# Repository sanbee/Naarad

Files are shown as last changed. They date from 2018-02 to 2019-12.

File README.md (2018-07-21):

# Naarad
A simple house monitor and control system. 

The *Naarad* system is a network of remote Nodes with a radio operating
in the [ISM band](https://en.wikipedia.org/wiki/ISM_band) and a Base
Station with an [RFM69CW](http://www.hoperf.com/rf_transceiver/modules/RFM69CW.html) (RFM) packet radio, currently connected to an
Arduino UNO.  The UNO talks to a Linux-based computer (currently a
Raspberry PI (RPi)) via the serial connection.  The RPi also listens
for incoming socket connections.  Commands for the *Naarad* network
are either generated at the RPi or arrive at the socket (e.g. from a
remotely connected device).  Commands meant for the UNO or the remote
Nodes are sent to the UNO via the serial connection.  The server on
the UNO then transmits the commands for the remote Nodes via the RFM
or via another radio for remote [OOK](https://en.wikipedia.org/wiki/On-off_keying)
devices.  Similarly, information from remote Nodes is received at the 
UNO via the RFM and immediately transferred to the RPi for consumption 
via the serial connection. The block level system diagram looks like this:

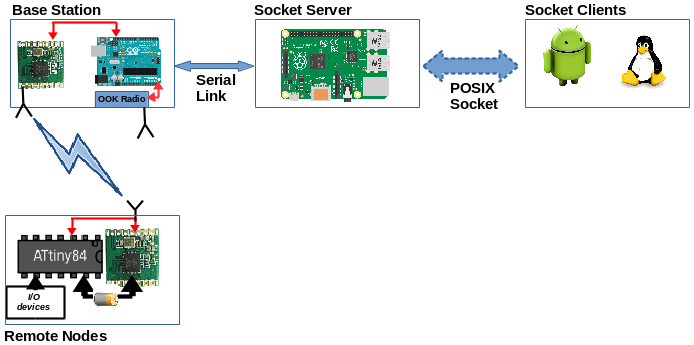
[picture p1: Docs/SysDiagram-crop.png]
SysDiagram


This repository has the code for the three components of the Naarad system: 
  * The code running on the MCUs on the remote nodes is in the [Nodes](Nodes) directory
  * The code running on the Arduino UNO on the Base Station is in the [BaseStation](BaseStation) directory
  * The code running on the central socket server (Raspberry Pi) is in the [RPi](RPi) directory

### Resources
The communication with the RFM is done using the
[JeeLib](https://github.com/jcw/jeelib) library from
[JeeLabs](https://jeelabs.org).

The communication hardware on the remote Nodes is derived from the
[TinyTx](https://nathan.chantrell.net/tinytx-wireless-sensor) design.
For programming the ATTiny84 using an Arduino, I followed the
instructions from [here](https://nathan.chantrell.net/20120225/an-attiny-based-wireless-temperature-sensor/).

[This](http://www.gammon.com.au/power) article by [Nick Gammon](http://www.gammon.com.au/forum/bbshowbio.php?bbuser_id=1) is an excellent resource for techniques to reduce power consumption on MCU. While the code here is for Arduino (Atmega328P), some of the techniques apply to other Atmel processors.  A similar article sepecifically for ATTiny84 would be great.  This also has a post with very useful information about batteries (including self-drainage rates etc.).

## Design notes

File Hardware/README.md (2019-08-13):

# Naarad Hardware

|  Prototype | Version 1 |
| :---: | :---: |
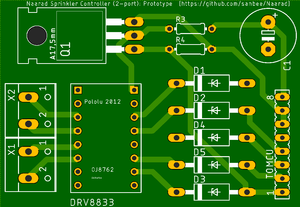
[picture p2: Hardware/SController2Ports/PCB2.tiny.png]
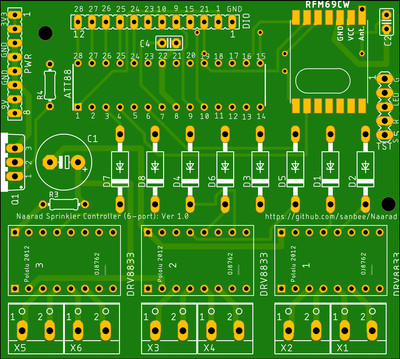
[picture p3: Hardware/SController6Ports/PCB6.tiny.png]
|   |   |

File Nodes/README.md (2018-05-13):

  * TinyTX: Code that runs on Tx-only remote monitor nodes
  * TinyL9110S: Code for the Sprinkler controller node.  This node
    does full duplex communication and uses the L9110S H-bridge to
    control a DC latching solenoid valve.
```
- From <ROOT>/
// ATMEL ATTINY84 / ARDUINO
//
//                           +-\/-+
//                     VCC  1|    |14  GND
//             (D  0)  PB0  2|    |13  PA0  (D 10)        AREF
//             (D  1)  PB1  3|    |12  PA1  (D  9) 
//             (D 11)  PB3  4|    |11  PA2  (D  8) 
//  PWM  INT0  (D  2)  PB2  5|    |10  PA3  (D  7) 
//  PWM        (D  3)  PA7  6|    |9   PA4  (D  6) 
//  PWM        (D  4)  PA6  7|    |8   PA5  (D  5)        PWM
//                           +----+
```

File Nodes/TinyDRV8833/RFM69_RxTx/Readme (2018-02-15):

This dir. has the sketch development for
 - Program the ATT84 on the RFM69 board to work in both Rx and Tx.
 - Identify command-packets from the server (NodeID 5) meant for
   itself (Node ID 15) and process them by LOW/HIGH on (A2,D8, Pin11)
   and (A3,D7, Pin12) on ATT84.

Branches:

master: Has the first working version
   SrvTxRetry: o Has ver0 code for pkt. ACK and retry at the server
                       o Takes only simple command: RFM_SEND NODE CMD

        FullCmd: o Has retry (SrvTxRetry)              [THIS IS THE VERSION ON THE MCU] 03FEB2018
	               o RFM_SEND CMD NODE PORT TIMEOUT
		       o SYS commands: Only SYS_SHUTDOWN_INTERVAL
	                  tested

              FullCmdTO_Untested:  o Has full command support
                                                     (FullCmd)
						  o UNTESTED code for
                                                     SYS_SHUTDOWN_INTERVAL_MULTIPLIER
						  o UNTESTED code for enabling valveTimeout

                                                     SYS_SHUTDOWN_INTERVAL_MULTIPLIER
                                                     is required since Sleepy::loseSomeTime()
                                                     can take a maximum of 60000 (60 sec.).  
                                                     With an 8-bit multiplier, it can remain shut
                                                     for max. of 60x255 sec.

                                                     Attempt for valveTimeout is to issue a
						     CLOSE command valveTimeout min. after
						     a OPEN command was issued. Default
						     value is 30min (1800000 milli sec).  If a
						     value of 0 is recevied as part of the
						     RFM_SEND command, it defaults to 30min.
	             
                                                  o unoserver2.ino has the ping command
 						     implemented and tested.  This is the
						     sketch running on Arduino now (5Feb2018).
TODO:
-------

0. The temperature reading does not look right.  Fix it.

1. Along with the command, send info. about when to toggle the
    solenoid.

2. Use an ACK-based communication with the base-station.  Tell the
    station the state of the solenoid.  This will need parsing of the
    payload values at the base station as well.

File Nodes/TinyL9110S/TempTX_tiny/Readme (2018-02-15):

A sketch to make the RFM69 break-out board act as a simple Naarad Tx-only node.

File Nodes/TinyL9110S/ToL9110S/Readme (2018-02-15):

This sketch is a standalone test for ATT84 to toggle the solenoid via L9110S connected to it on pins (11,12).
This just toggles the Pin11 and Pin12 every 10 sec.

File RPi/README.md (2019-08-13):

# Naarad Host Server

The block level diagram of the server looks like this:

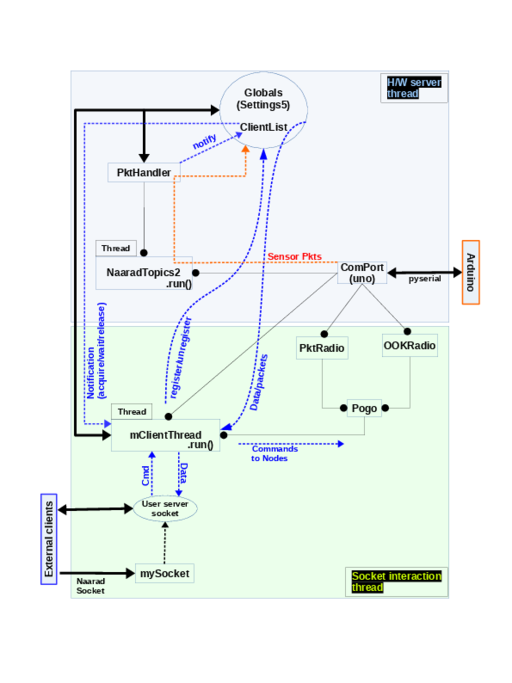
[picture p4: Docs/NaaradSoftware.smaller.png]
SysDiagram


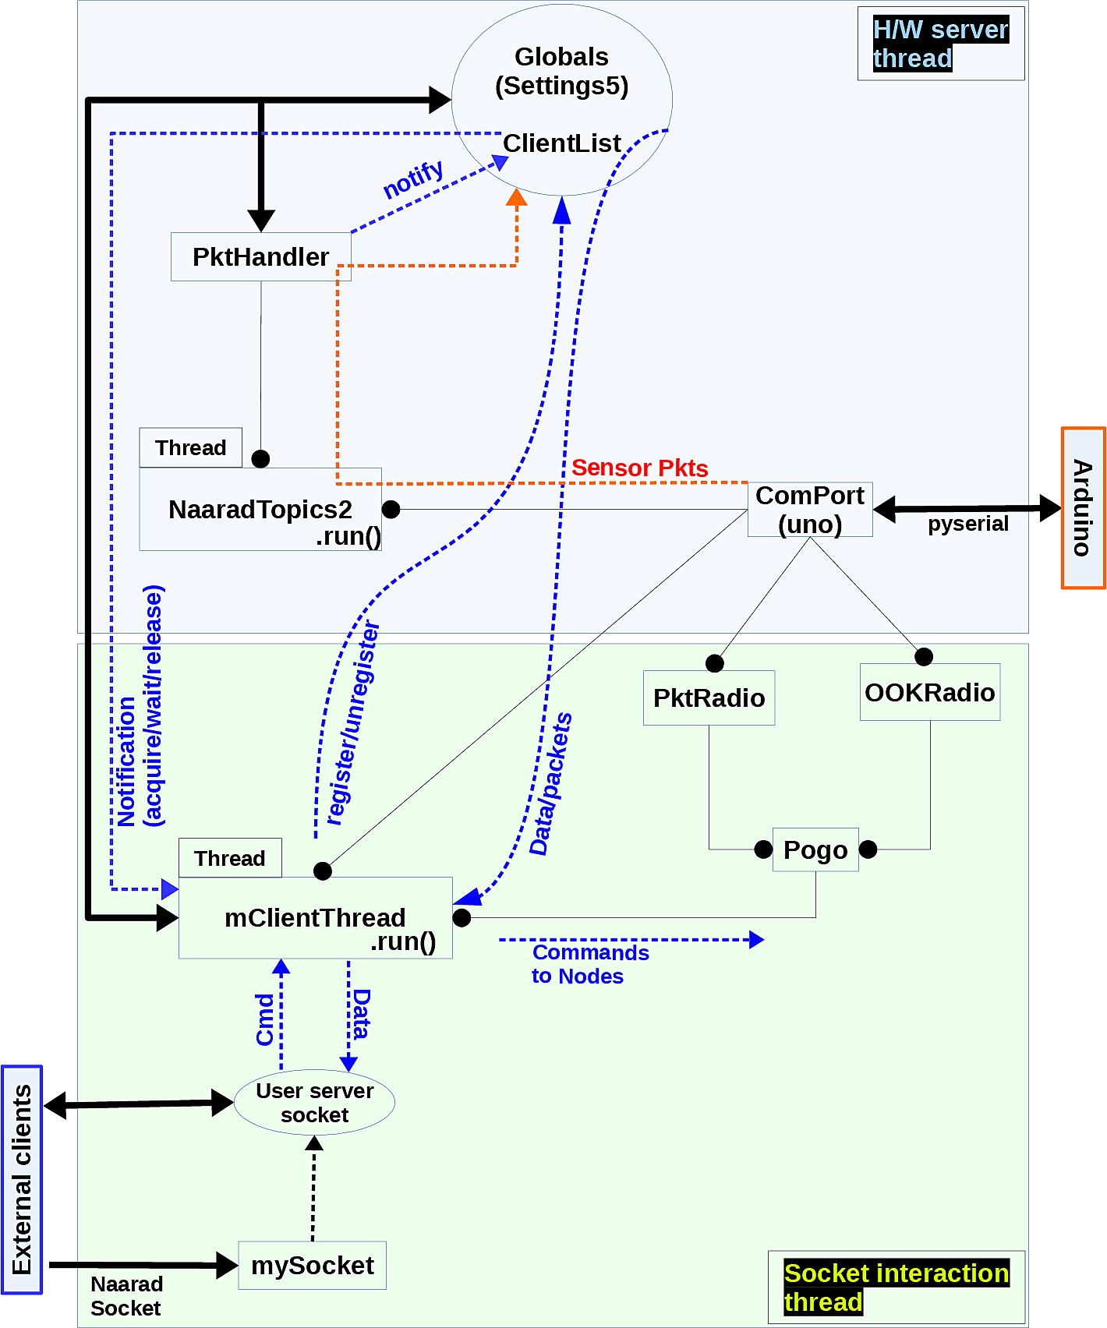
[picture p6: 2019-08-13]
Docs/NaaradSoftware.png

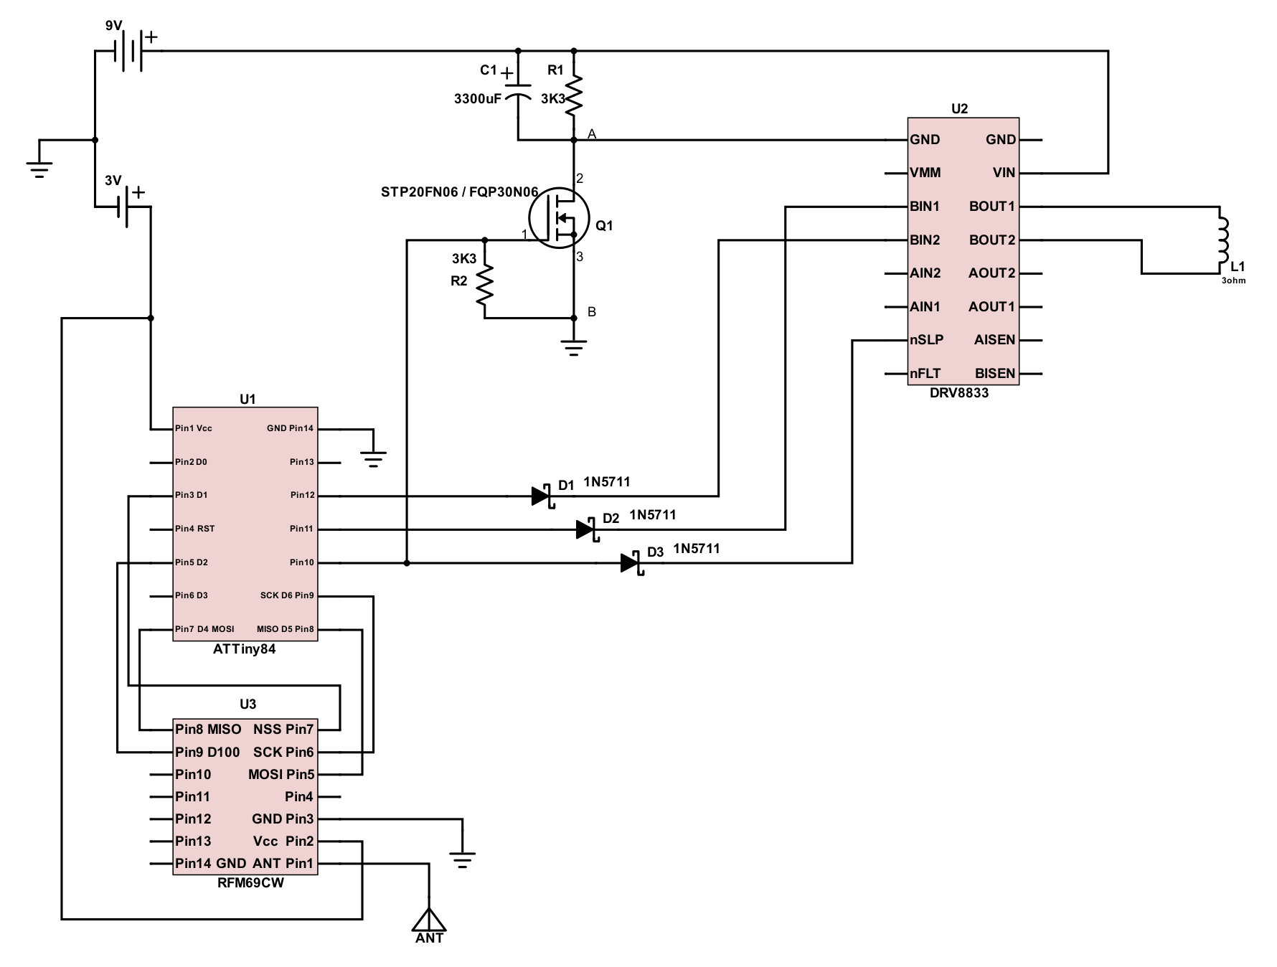
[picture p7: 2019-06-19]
Docs/SController-8833.png

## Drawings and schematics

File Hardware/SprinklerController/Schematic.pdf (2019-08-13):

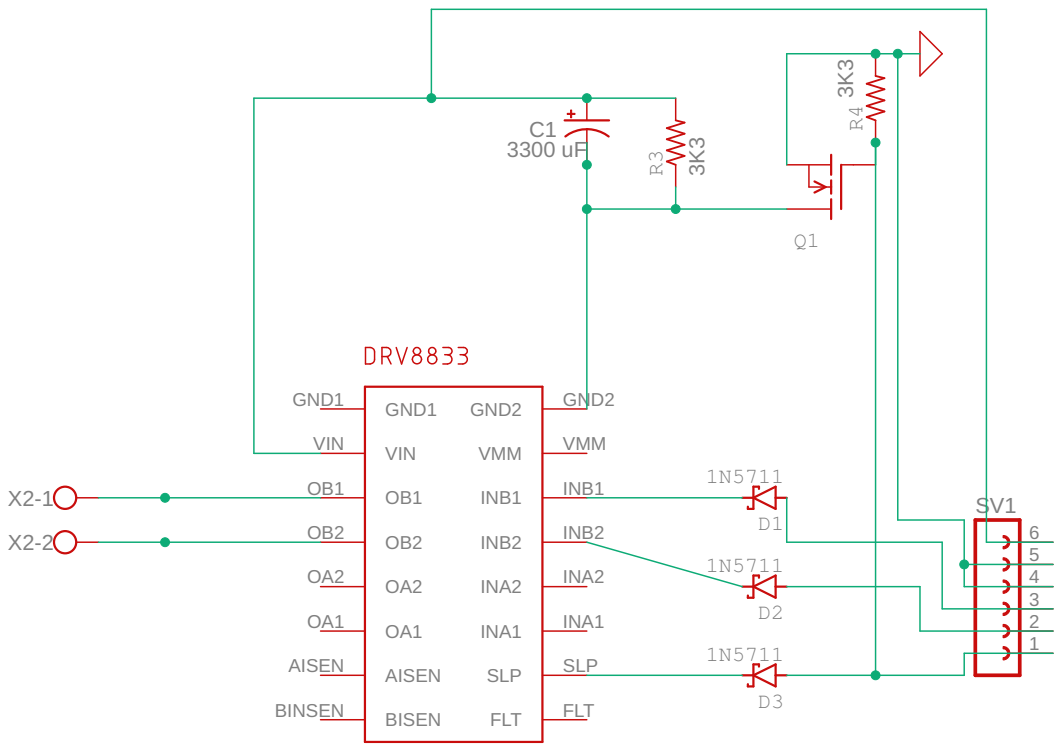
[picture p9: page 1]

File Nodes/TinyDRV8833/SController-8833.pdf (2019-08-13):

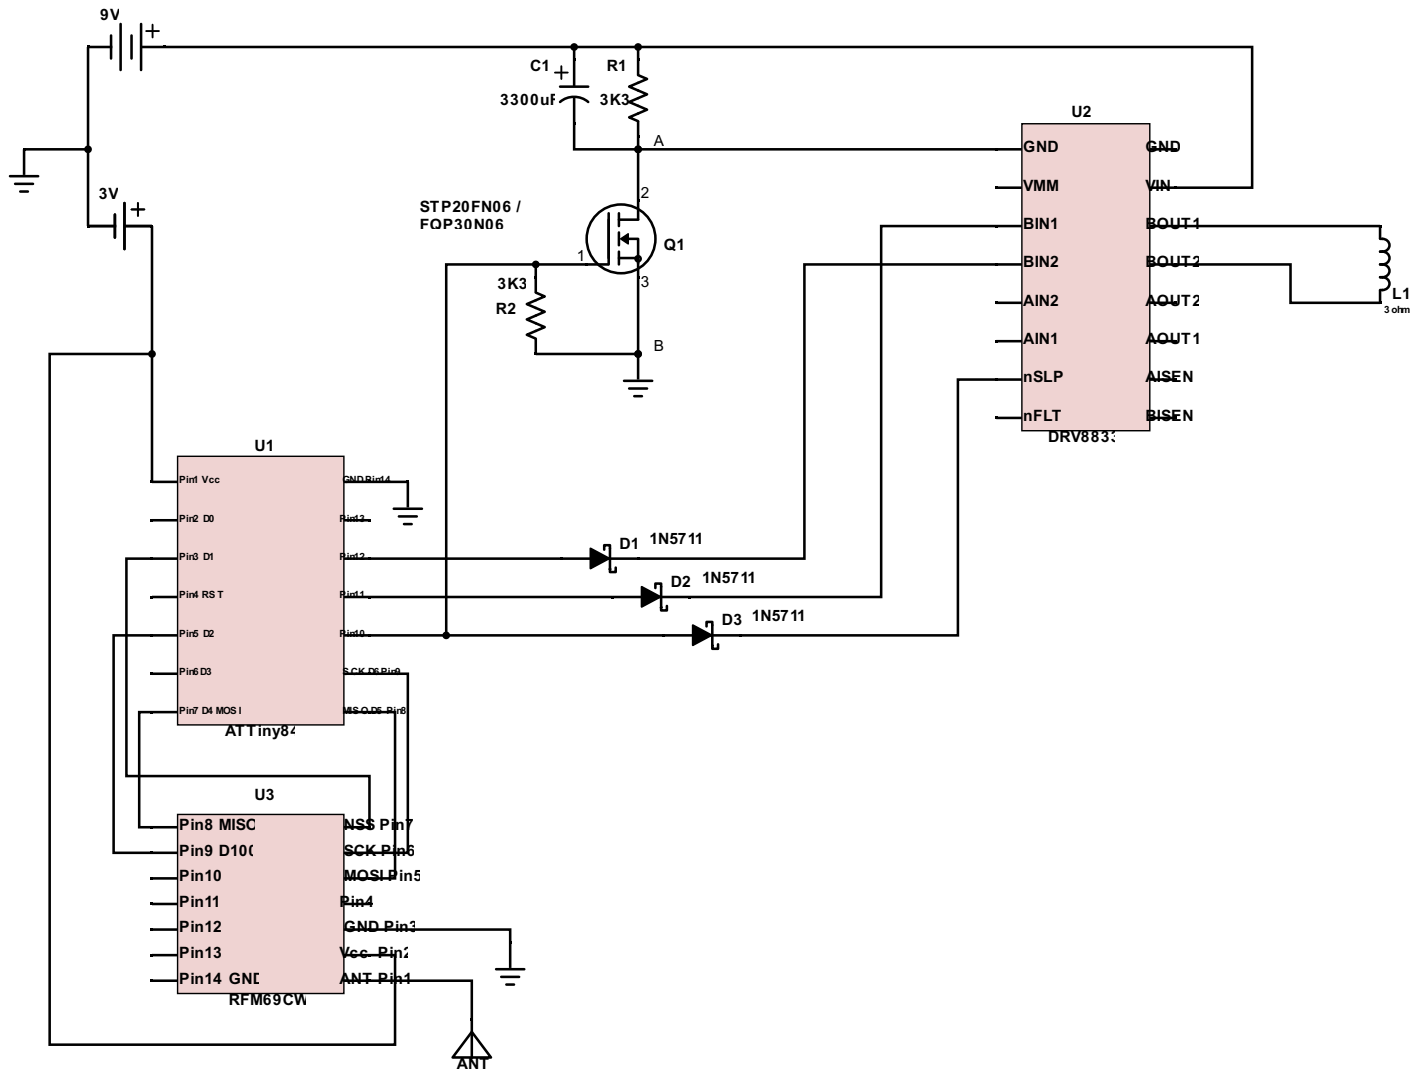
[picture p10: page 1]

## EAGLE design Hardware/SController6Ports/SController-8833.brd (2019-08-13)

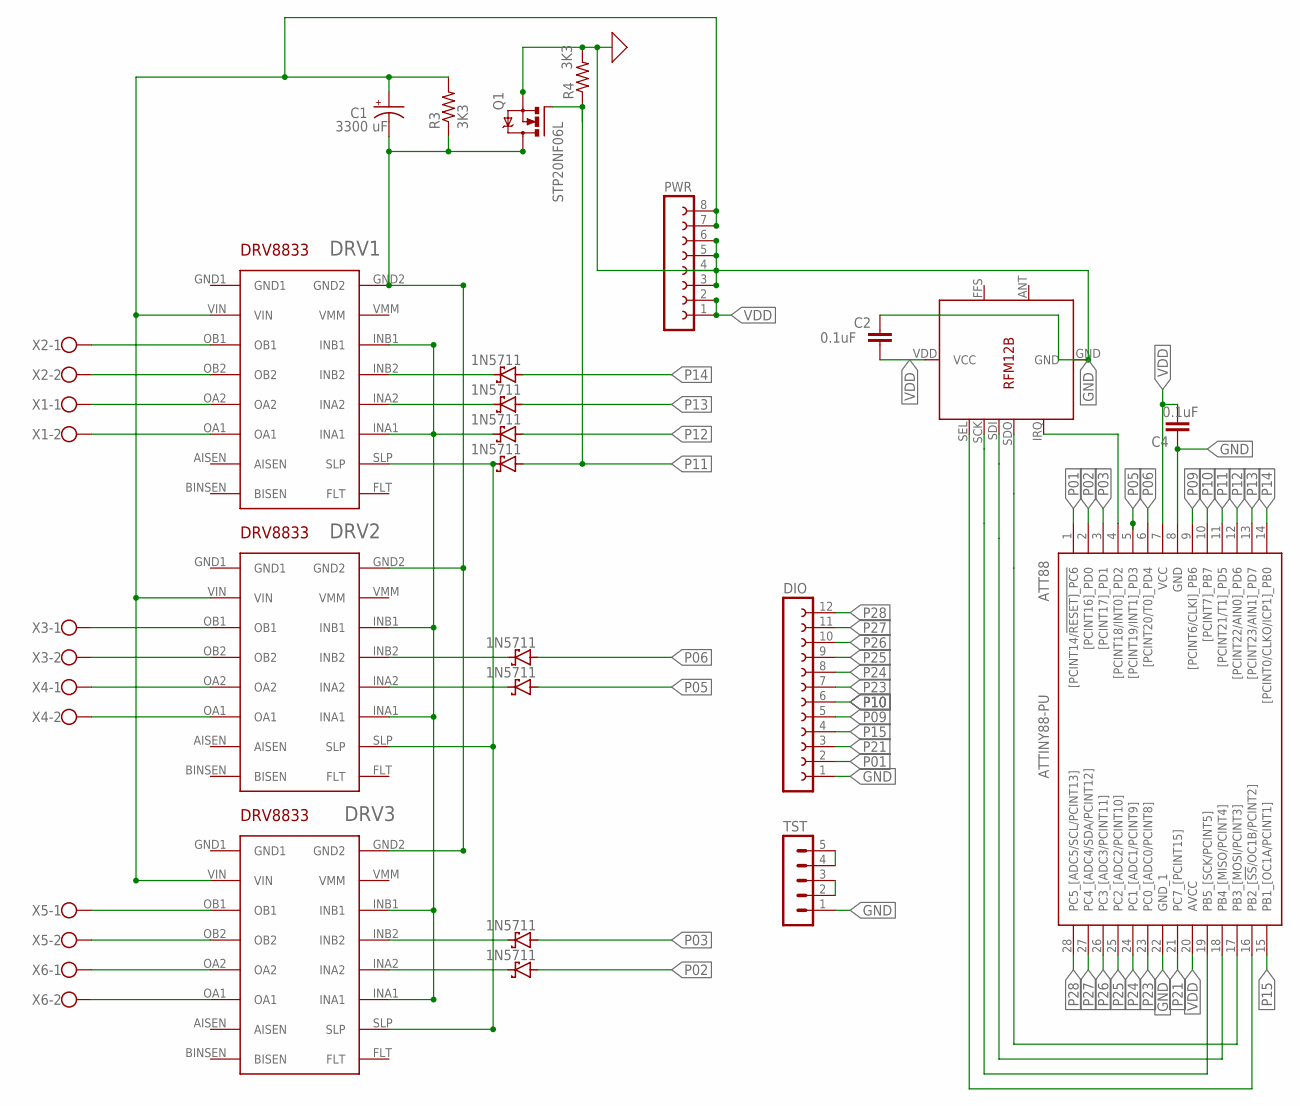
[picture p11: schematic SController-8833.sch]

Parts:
1: DRV1; POLOLU-DRV8833
2: DRV2; POLOLU-DRV8833
3: DRV3; POLOLU-DRV8833
ATT88: ATTINY88-PU; DIP794W53P254L3467H457Q28N
C1: 3300 uF; E5-10,5
C2, C4: 0.1uF; C2.5-2
D1, D2, D3, D4, D5, D6, D7, D8: 1N5711; F126Z12
DIO: FE12-1; FE12
PWR: FE08-1; FE08
Q1: STP20NF06L; TO220BV
R3, R4: 3K3; 0204/7
RFM69CW: RFM69CW; RFM12B
TST: MA05-1
X1, X2, X3, X4, X5, X6: W237-102

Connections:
CMN1: 1.INA1, 1.INB1, 2.INA1, 2.INB1, 3.INA1, 3.INB1, D3.C
GND: ATT88.8 (GND), ATT88.22 (GND_1), C2.2, C4.1, DIO.1, PWR.3, PWR.4, PWR.5, PWR.6, Q1.S, R4.2, RFM69CW.GND, TST.1
IRQ: ATT88.4 ([PCINT18/INT0]_PD2), RFM69CW.IRQ
unnamed: 2.INB2, D5.C
unnamed: 1.INB2, D1.C
unnamed: TST.4, TST.5
unnamed: TST.2, TST.3
unnamed: 1.INA2, D2.C
unnamed: 3.INB2, D7.C
unnamed: 2.INA2, D6.C
unnamed: 3.INA2, D8.C
OA11: 1.OA1, X1.2
OA12: 2.OA1, X4.2
OA13: 3.OA1, X6.2
OA21: 1.OA2, X1.1
OA22: 2.OA2, X4.1
OA23: 3.OA2, X6.1
OB11: 1.OB1, X2.1
OB12: 2.OB1, X3.1
OB13: 3.OB1, X5.1
OB21: 1.OB2, X2.2
OB22: 2.OB2, X3.2
OB23: 3.OB2, X5.2
P01: ATT88.1 ([PCINT14/!RESET]_PC6), DIO.2
P02: ATT88.2 ([PCINT16]_PD0), D8.A
P03: ATT88.3 ([PCINT17]_PD1), D7.A
P05: ATT88.5 ([PCINT19/INT1]_PD3), D6.A
P06: ATT88.6 ([PCINT20/T0]_PD4), D5.A
P09: ATT88.9 ([PCINT6/CLKI]_PB6), DIO.5
P10: ATT88.10 ([PCINT7]_PB7), DIO.6
P11: ATT88.11 ([PCINT21/T1]_PD5), D4.A, Q1.G, R4.1
P12: ATT88.12 ([PCINT22/AIN0]_PD6), D3.A
P13: ATT88.13 ([PCINT23/AIN1]_PD7), D2.A
P14: ATT88.14 ([PCINT0/CLKO/ICP1]_PB0), D1.A
P15: ATT88.15 (PB1_[OC1A/PCINT1]), DIO.4
P21: ATT88.21 (PC7_[PCINT15]), DIO.3
P23: ATT88.23 (PC0_[ADC0/PCINT8]), DIO.7
P24: ATT88.24 (PC1_[ADC1/PCINT9]), DIO.8
P25: ATT88.25 (PC2_[ADC2/PCINT10]), DIO.9
P26: ATT88.26 (PC3_[ADC3/PCINT11]), DIO.10
P27: ATT88.27 (PC4_[ADC4/SDA/PCINT12]), DIO.11
P28: ATT88.28 (PC5_[ADC5/SCL/PCINT13]), DIO.12
SCK: ATT88.19 (PB5_[SCK/PCINT5]), RFM69CW.SCK
SDI: ATT88.18 (PB4_[MISO/PCINT4]), RFM69CW.SDI
SDO: ATT88.17 (PB3_[MOSI/PCINT3]), RFM69CW.SDO
SEL: ATT88.16 (PB2_[!SS!/OC1B/PCINT2]), RFM69CW.SEL
SLP: 1.SLP, 2.SLP, 3.SLP, D4.C
VDD: ATT88.7 (VCC), ATT88.20 (AVCC), C2.1, C4.2, PWR.1, PWR.2, RFM69CW.VDD (VCC)
VGND: 1.GND2, 2.GND2, 3.GND2, C1.-, Q1.D, R3.1
VIN: 1.VIN, 2.VIN, 3.VIN, C1.+, PWR.7, PWR.8, R3.2

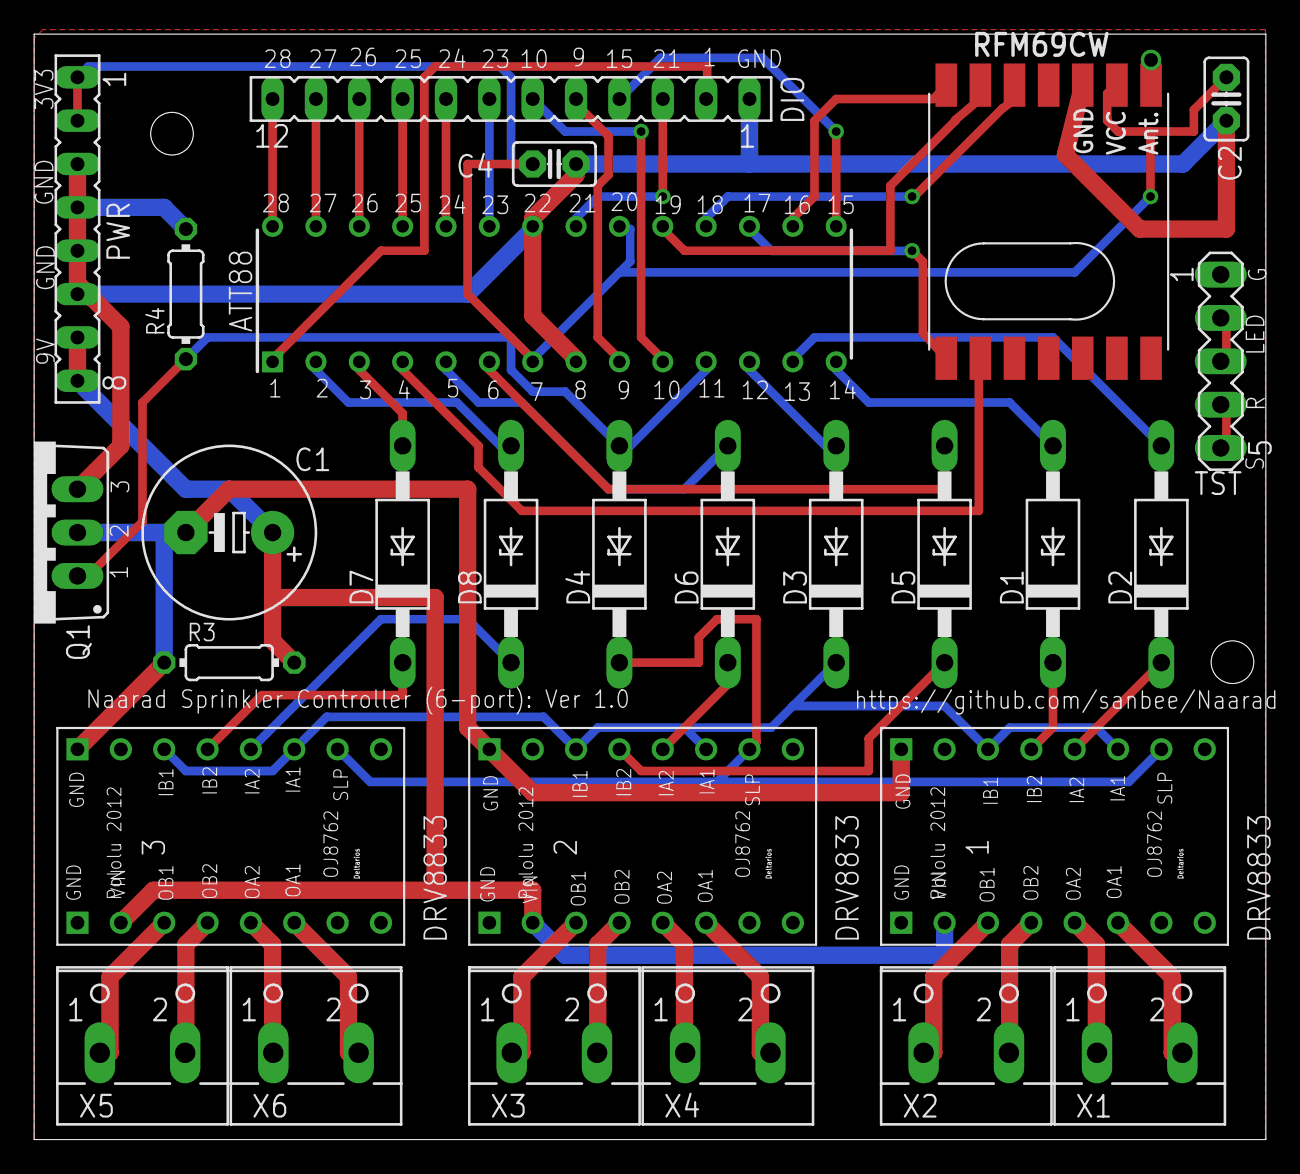
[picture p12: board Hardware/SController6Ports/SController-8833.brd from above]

Board: 2 copper layers, 72.2 x 64.8 mm, 28 parts (0 on the bottom side), 50 nets.

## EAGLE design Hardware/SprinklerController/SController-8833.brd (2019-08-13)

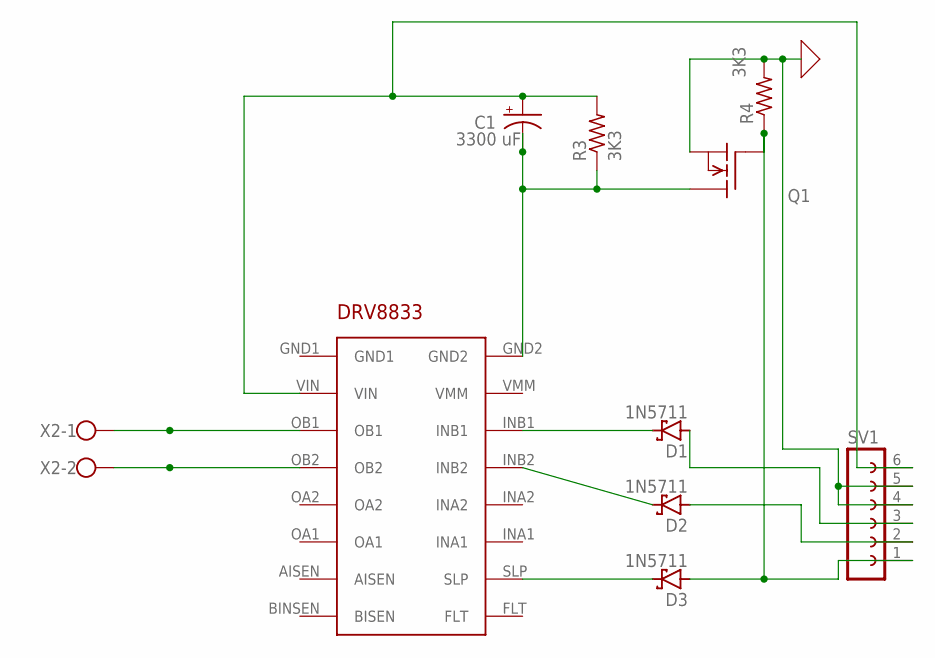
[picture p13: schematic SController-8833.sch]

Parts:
"": POLOLU-DRV8833
C1: 3300 uF; E5-10,5
D1, D2, D3: 1N5711; F126Z12
Q1: SUP75N06-08; TO220
R3: 3K3; 0204/7
R4: R-US_0204/7; 0204/7
SV1: FE06-1; FE06
X2: W237-102

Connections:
0: Q1.3 (S), R4.2, SV1.4, SV1.5
unnamed: "".INB1, D1.C
unnamed: "".INB2, D2.C
unnamed: "".SLP, D3.C
unnamed: "".VIN, C1.+, R3.2, SV1.6
unnamed: "".GND2, C1.-, Q1.2 (D), R3.1
unnamed: "".OB1, X2.1
unnamed: D3.A, Q1.1 (G), R4.1, SV1.1
unnamed: D2.A, SV1.2
unnamed: "".OB2, X2.2
unnamed: D1.A, SV1.3

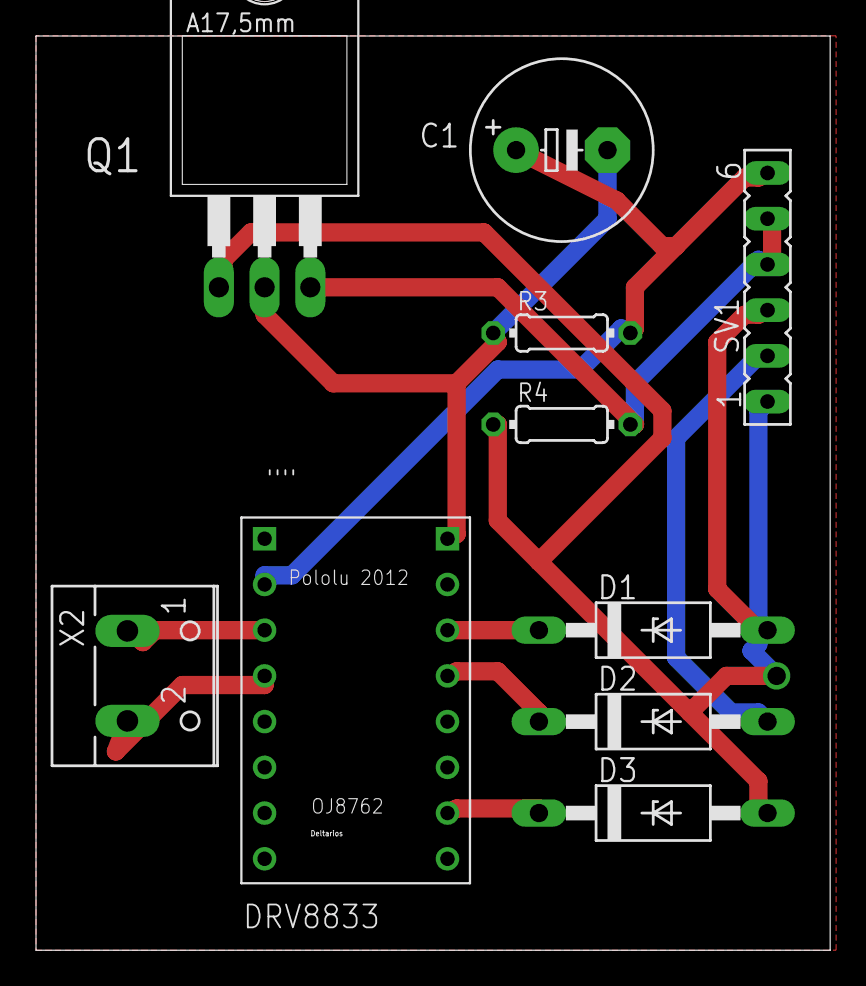
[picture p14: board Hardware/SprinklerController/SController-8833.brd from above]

Board: 2 copper layers, 44.1 x 50.8 mm, 10 parts (0 on the bottom side), 11 nets.

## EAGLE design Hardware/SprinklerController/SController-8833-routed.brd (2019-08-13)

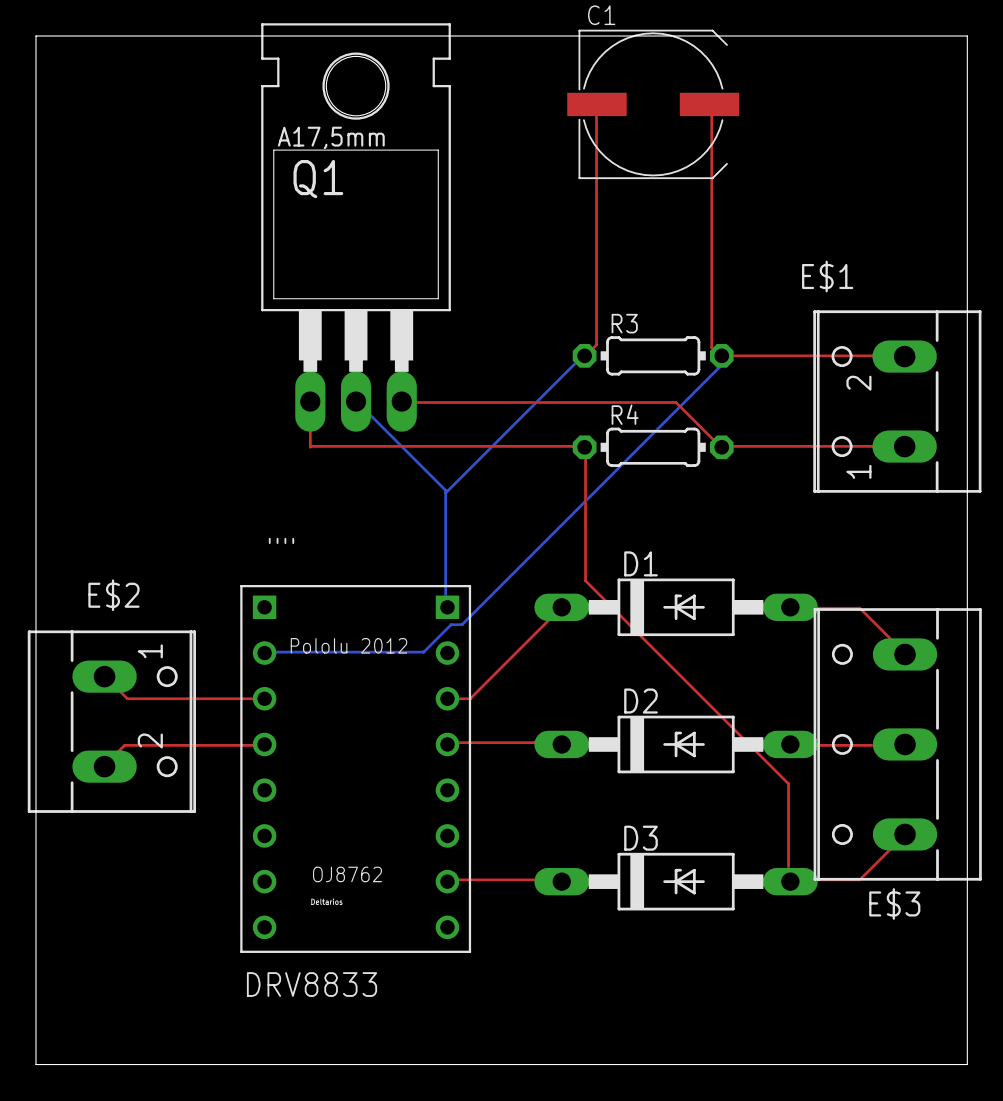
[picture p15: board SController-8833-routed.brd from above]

Board: 2 copper layers, 51.7 x 57.1 mm, 11 parts (0 on the bottom side), 11 nets.

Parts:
"": POLOLU-DRV8833
C1: 3300 uF; UD-8X10_NICHICON
D1, D2, D3: 1N5711; F126Z12
E$1, E$2: W237-102
E$3: W237-103
Q1: SUP75N06-08; TO220
R3, R4: 0204/7

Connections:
0: E$1.1, Q1.3, R4.2
unnamed: "".INB1, D1.C
unnamed: "".INB2, D2.C
unnamed: "".SLP, D3.C
unnamed: "".VIN, C1.+, E$1.2, R3.2
unnamed: "".GND2, C1.-, Q1.2, R3.1
unnamed: D3.A, E$3.1, Q1.1, R4.1
unnamed: D1.A, E$3.3
unnamed: D2.A, E$3.2
S$1: "".OB1, E$2.1
S$2: "".OB2, E$2.2

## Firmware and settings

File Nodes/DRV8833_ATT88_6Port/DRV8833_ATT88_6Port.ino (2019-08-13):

// -*- C++ -*-
// --------------------------------------------------------------------------------------
// ATtiny84 Based Wireless temperature sensor (based on Tiny-Tx) and
// sprinkler controller for DC latching solenoids.
// By S. Bhatnagar (sanbeepie@gmail.com).
//
// GNU GPL V3
//--------------------------------------------------------------------------------------
// Connections between ATTiny84 MCU and the RFM69CW module:
//
//       ATT84          RFM69CW
//         D1             NSS
//         D2             DI00
//      MOSI, D4          MISO
//      MISO, D5          MOSI
//      SCK, D6           SCK
//
// Will these same connection also work when ATT84 is programmed for
// both Rx and Tx?

#define RF69_COMPAT 1
#pragma message("Compiling in RF69_COMPAT mode")
#include <JeeLib.h> // https://github.com/jcw/jeelib
#include <avr/power.h>
#include "RemoteCmd.h" // List of remote commands
ISR(WDT_vect) { Sleepy::watchdogEvent(); } // interrupt handler for JeeLabs Sleepy power saving

#define SERVER_NODE_ID 5
#define MY_NODE_ID     16                     // RF12 node ID in the range 1-30
#define network        210                   // RF12 Network group
#define freq           RF12_433MHZ  // Frequency of RFM12B module

#define SLP    PIN_D5  // D6 (AT88 pin 11)
#define COMMN  PIN_D6  // D6 (AT88 pin 12) IB1_0, IA1_0, IB1_1, IA1_1, IB1_2, IA1_2
#define PORT0  PIN_B0  // B0 (AT88 pin 14) IB2_0
#define PORT1  PIN_D7  // D7 (AT88 pin 13) IA2_0
#define PORT2  PIN_D4  // D4 (AT88 pin 06) IB2_1
#define PORT3  PIN_D3  // D3 (AT88 pin 05) IA2_1
#define PORT4  PIN_D1  // D1 (AT88 pin 03) IB2_2
#define PORT5  PIN_D0  // D0 (AT88 pin 02) IA2_2

int RFM69_READ_TIMEOUT = 3000, // 3 sec 
  SYS_SHUTDOWN_INTERVAL=60000, // 60 sec
  SYS_SHUTDOWN_INTERVAL_MULTIPLIER=1,
  VALVE_PULSE_WIDTH=10,
  PULSE_WIDTH_MULTIPLIER=1; // 10 ms

#define RCV_TIMEDOUT      10
#define RCV_GOT_SOME_PKT  20
#define RCV_GOT_VALID_PKT 30

// Macros to extrat NodeID, Port No., Command and Timeout values
// packed in the int-elements of the PayLoad struct.
// #define GET_NODEID(p)   ((p.supplyV) & (0xFF)) /* Bits 0-7 */
// #define GET_PORT(p)     ((p.supplyV) >> (8) & (0xFF)) /* Bits 8-15 */
// #define GET_CMD(p)      ((p.temp) & (0xFF)) /* Bits 0-7 */
// #define GET_TIMEOUT(p)  ((p.temp) >> (8) & (0b1111)) /*  Bits 8-15 */


inline static short int getNibble(short int target, short int which)
{
  return (target >> (which*8)) & (0xFF);
}
#define GET_CMD(p)      (getNibble(p.supplyV,1))
#define GET_NODEID(p)   (getNibble(p.supplyV,0))
#define GET_PORT(p)     (getNibble(p.temp,1))
#define GET_TIMEOUT(p)  (getNibble(p.temp,0))
#define GET_PARAM1(p)   (getNibble(p.temp,1)) /* Get the parameter for the SET_* commands*/
#define GET_PARAM0(p)   (getNibble(p.temp,0)) /* Get the parameter for the SET_* commands*/

#define N_PORT_CTRL_BITS_D 7
#define N_PORT_CTRL_BITS_B 1
static const byte portD2BitMap[N_PORT_CTRL_BITS_D]={0,1,3,4,5,6,7}; //Pins: D0, D1, D3, D4, D5, D6, D7
static const byte portB2BitMap[N_PORT_CTRL_BITS_B]={0};             //Pins: B0



// Utility macros
// #define adc_disable() (ADCSRA &= ~(1<<ADEN)) // disable ADC (before power-off)
// #define adc_enable()  (ADCSRA |=  (1<<ADEN)) // re-enable ADC
//bitClear(PRR, PRADC); ADCSRA |= bit(ADEN); // Enable the ADC
//ADCSRA &= ~ bit(ADEN); bitSet(PRR, PRADC); // Disable the ADC to save power
  

byte dataReady=0;
unsigned long lastRF;                    // used to check for RF recieve failures
int payload_nodeID;
//###################
//Data Structure to be sent
//###################

typedef struct
{
  int temp;	// Temperature reading: re-used for receiving cmd
  int supplyV;	// Supply voltage; re-used for receiving target nodeID
 } Payload;

int tempReading,cmd=-1, port=0;
unsigned long valveTimeout=60000,TimeOfLastValveCmd=0; /*1 min*/
Payload payLoad_RxTx;
uint16_t freqOffset=1600;

//#################################################################
void setup()
{
  // rf12_initialize(MY_NODE_ID,freq,network,freqOffset); // Initialize RFM12 with settings defined above 
  // rf12_sleep(0);                          // Put the RFM12 to sleep

  analogReference(INTERNAL);  // Set the aref to the internal 1.1V reference
 
  pinMode(SLP,   OUTPUT);
  pinMode(COMMN, OUTPUT);
  pinMode(PORT0, OUTPUT);
  pinMode(PORT1, OUTPUT);
  pinMode(PORT2, OUTPUT);
  pinMode(PORT3, OUTPUT);
  pinMode(PORT4, OUTPUT);
  pinMode(PORT5, OUTPUT);

  byte port;
  // CLOSE all ports.  This generates a 10ms pulse which draws current
  // and therefore must be done one port at a time.
  for(port=0;port<N_PORT_CTRL_BITS_D;port++)
    setSolenoid(CLOSE,port); 
  // Set A0-3, A7 and B0 to LOW
  setPortD(port,0x00);PORTD=port;
  setPortB(port,0x00);PORTB=port;
  SYS_SHUTDOWN_INTERVAL_MULTIPLIER=2*24*60; //minutes in 2 days
  SYS_SHUTDOWN_INTERVAL=60000; // One minute -- close to the maximum possible with looseSomeTime()
  Sleepy::loseSomeTime(5000); //JeeLabs power save function: enter low power mode for 60 seconds (valid range 16-65000 ms)
  
  //  power_adc_enable();
}
//#################################################################
void loop()
{
  for(byte port=0;port<N_PORT_CTRL_BITS_D;port++)
    {
      setSolenoid(OPEN,port,portD2BitMap); // This generates a 10ms pulse which draws current
      hibernate(60000,1);
      setSolenoid(CLOSE,port,portD2BitMap);// This generates a 10ms pulse which draws current
      hibernate(5000,1);
    }

  //power_adc_disable();//Claim is that with this, the current consumption is down to 0.2uA from 230uA (!)
  hibernate(SYS_SHUTDOWN_INTERVAL,SYS_SHUTDOWN_INTERVAL_MULTIPLIER);
}

void hibernate(const unsigned int& timeout, const unsigned int& multiplier)
{
  power_adc_disable();
  for(unsigned int i=0;i<multiplier;i++)
    Sleepy::loseSomeTime(timeout); //JeeLabs power save function: enter low power mode for 60 seconds (valid range 16-65000 ms)
  power_adc_enable();
}


#define MASK_PORTD 0b11011111 //Only bits with 1 will be modified
#define MASK_PORTB 0b10000000 //Only bits with 1 will be modified
#define SETBIT(t,n)  (t |= 1<<n)
#define CLRBIT(t,n)  (t &= ~(1 << n))
#define getPORTD() (PORTD)
#define getPORTB() (PORTB)
void setPortD(byte& port,const byte& val)
{
  port = (port & ~MASK_PORTD) | (val & MASK_PORTD);
}

void setPortB(byte& port,const byte& val)
{
  port = (port & ~MASK_PORTB) | (val & MASK_PORTB);
}

void setSolenoid(const byte& cmd, const byte& port, const byte& bitMap)
{
  byte CommonPin=0, Pin1=0;
  // portD and portB values should be set to whatever is the current
  // value of PORTD and PORTB registers.
  byte portD=getPORTD(), portB=getPORTB();
  // If CommonPin is 1, B0 and A0-3,A7 should be set to 1. Since the
  // bits that can change in PORTD and PORTB is controlled by
  // MASK_PORTD and MASK_PORTB, setting CommonPin=0b11111111 and then
  // blindly using it to set the bits in PORTD and PORTB will work.
  if      (cmd == OPEN)  {CommonPin=0xFF; Pin1=0;}
  else if (cmd == CLOSE) {CommonPin=0;  Pin1=1;} 

  // printf("P, S, C: %d %d %d\n",port2BitMap[port], (CommonPin==-1)?1:0, Pin1);

  // Set both pins of all ports to the same value as the CommonPin
  // value, effectively issuing the SHUT command to all ports.  No
  // current should be drawn from the battery by any of the ports in
  // this state
  setPortB(portB, CommonPin);
  setPortD(portD, CommonPin);

  // Now set the other pin of the specific port.  port2BitMap maps the
  // port number to the bits in the PORTD.
  if (Pin1==1) SETBIT(portD,bitMap[port]);
  else         CLRBIT(portD,bitMap[port]);
    
  // Finally, copy the pin settings to PORTD and PORTB registers.  The
  // lines below actually sets the hardware.
  PORTD=portD;
  PORTB=portB;
  // printf("B: "); showbits(PORTB);
  // printf("A: "); showbits(PORTD);
  // printf("Insert 10ms delay\n");

  // 10ms later, remove the voltage (issue the SHUT command)
  delay(10);
  setPortD(portD,0x00);
  CLRBIT(portB, 0);//setPortB(PORTB,0x00);
  PORTD=portD;
  PORTB=portB;
  delay(10);
}
//
//#################################################################
//#################################################################
//
// Application specific functions
// static void controlSolenoid(const int cmd)
// {
//   // First handle system commands (these modify the internal
//   // parameters, but don't control the valve solenoid.  THESE SHOULD
//   // IMMEDIATELY RETURN AFTER SERVICING THE COMMANDS.
//   if (cmd==NOOP) return;
//   if (cmd==SET_RX_TO)                          {RFM69_READ_TIMEOUT = 1000*GET_PARAM1(payLoad_RxTx);return;} // Default 3 sec.
//   if (cmd==SET_TX_INT)
//     {
//       SYS_SHUTDOWN_INTERVAL = 1000*GET_PARAM1(payLoad_RxTx); // Default 60 sec.
//       SYS_SHUTDOWN_INTERVAL_MULTIPLIER=GET_PARAM0(payLoad_RxTx);
//       SYS_SHUTDOWN_INTERVAL_MULTIPLIER=((SYS_SHUTDOWN_INTERVAL_MULTIPLIER==0)?1:SYS_SHUTDOWN_INTERVAL_MULTIPLIER);
//       return;
//     };
//   if (cmd== SET_VALVE_PULSE_WIDTH)
//     {
//       VALVE_PULSE_WIDTH = GET_PARAM1(payLoad_RxTx); // Default 10 ms.
//       PULSE_WIDTH_MULTIPLIER = GET_PARAM0(payLoad_RxTx);//Detaul 1
//       return;
//     };
//   //
//   // Service the solenoid control commands
//   //
//   if (cmd==OPEN)
//     {
//       digitalWrite(SOLENOID_CTL0, HIGH);
//       digitalWrite(SOLENOID_CTL1, LOW);
//       for(byte i=0;i<PULSE_WIDTH_MULTIPLIER;i++) delay(VALVE_PULSE_WIDTH);
//       TimeOfLastValveCmd=millis(); // Record the time when OPEN command is issued.
//     }
//   else if (cmd==CLOSE)
//     {
//       digitalWrite(SOLENOID_CTL0, LOW);
//       digitalWrite(SOLENOID_CTL1, HIGH);
//       for(byte i=0;i<PULSE_WIDTH_MULTIPLIER;i++) delay(VALVE_PULSE_WIDTH);
//       TimeOfLastValveCmd=0; // Record that the valve is off now
//     }
//   //  else //Comment this line, and uncomment the delays in above blocks
//        //to ensure that OPEN and CLOSE are always followed by a delay
//        //and SHUT
//     {
//       digitalWrite(SOLENOID_CTL0, LOW);
//       digitalWrite(SOLENOID_CTL1, LOW);
//       TimeOfLastValveCmd=0; // Record that the valve is off now
//     }
// }

// //--------------------------------------------------------------------------------------------------
// // Send payload data via RF
// //--------------------------------------------------------------------------------------------------
// static void rfwrite(const byte wakeup)
//  {
//    if (wakeup==1) rf12_sleep(-1);     //wake up RF module
//    while (!rf12_canSend()) rf12_recvDone();
//    rf12_sendStart(0, &payLoad_RxTx, sizeof payLoad_RxTx); 
//    rf12_sendWait(1);    //wait for RF to finish sending while in IDLE (1) mode (standby is 2 -- does not work with JeeLib 2018)
//    rf12_sleep(0);    //put RF module to sleep
// }

// //--------------------------------------------------------------------------------------------------
// // Read current supply voltage
// //--------------------------------------------------------------------------------------------------
// static long readVcc()
//  {
//    long result;
//    // Read 1.1V reference against Vcc
//    ADMUX = _BV(MUX5) | _BV(MUX0);
//    delay(2); // Wait for Vref to settle
//    ADCSRA |= _BV(ADSC); // Convert
//    while (bit_is_set(ADCSRA,ADSC));
//    result = ADCL;
//    result |= ADCH<<8;
//    result = 1126400L / result; // Back-calculate Vcc in mV
//    return result;
// }

// static int readRFM69() 
// {
//   //  digitalWrite(LEDPIN,LOW);    // turn LED off
  
//   // On data receieved from rf12
//   //################################################################
  
//   //  if (rf12_recvDone() && rf12_crc == 0 && (rf12_hdr & RF12_HDR_CTL) == 0) 
//   if (rf12_recvDone() && rf12_crc == 0)
//     {
//       payload_nodeID = rf12_hdr & 0x1F;   // extract node ID from received packet
//       payLoad_RxTx=*(Payload*) rf12_data; // Get the payload

//       dataReady = 1;                   // Ok, data is ready
      
//       if ((payload_nodeID != SERVER_NODE_ID) && (GET_NODEID(payLoad_RxTx) != MY_NODE_ID)) return -1;

//       cmd=GET_CMD(payLoad_RxTx);
//       port=GET_PORT(payLoad_RxTx);
//       valveTimeout=GET_TIMEOUT(payLoad_RxTx)*60*1000;//Convert user value in min. to milli sec.
//       valveTimeout=(valveTimeout==0?60000:valveTimeout);

//       if (cmd == 0)      return CLOSE;
//       else if (cmd == 1) return OPEN;
//       else if (cmd== 2) return SHUT;
//       else return cmd;
//     }
//     return -1;
// }

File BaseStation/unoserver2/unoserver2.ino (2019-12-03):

/* -*-C++-*- */
//--------------------------------------------------------------------------------------
// ATtiny84 based wireless sensor (based on Tiny-Tx) and sprinkler
// controller for DC latching solenoids.
// By S. Bhatnagar (sanbeepie@gmail.com)
//
// GNU GPL V3
//--------------------------------------------------------------------------------------
// This code accepts RFM_SEND command with the following usage:
//     RFM_SEND CMD NODEID PARAM1 PARAM0
//        CMD:     See RemoteCmd.h for details
//        NODEID:  The target node ID
//        PARAM1:  The port on the target node.
//                 Each node can have multiple ports/solenoids
//        PARAM0:  The time in integral number of minutes, after which the
//                 solenoid will be CLOSED and the port SHUT (both control pins LOW)
//
// See RemoteCmd.h for details on various values of CMD, PARAM1 and PARAM2. 
//
// The parameters are packed in the two integers of the Payload struct:
//
//              NODEID CMD        PARAM1 PARAM0
//    Byte No.    1     0            1     0
//             Payload.supplyV      Payload.rx1
//
// The macros SET/GET_{CMD,NODEID,PORT,TIMEOUT} do the packing/unpacking.
//
// This code also has a SEND-ACK protocol for RFM_SEND. The remote
// node echos the RFM_SEND command as soon as it gets it. The RFM_SEND
// command is re-send for N_TRILS number of trials if this ACK packet
// from the remote node is not received.  The resend will continue on
// the arrival of a packet (containing the sensor values) from the
// remote node till an ACK is received.
//
#define SEQ_LEN 35

#define outputRFTxPin  6
#define sensorTMP36Pin  0 //the analog pin the TMP36's Vout (sense) pin is connected to
char cmdStr[SEQ_LEN];
char seqReady = 0;
char serialCount;

//####################################################################
//####################################################################
//####################################################################
#define RF69_COMPAT 1
#if RF69_COMPAT == 1
#pragma message("Compiling in RF69_COMPAT")
#endif
#include <JeeLib.h>    // https://github.com/jcw/jeelib


#include "RemoteCmd.h"// The remote commands for sprinkler controller
#include <Queue.h>
//MilliTimer sendTimer;

// Fixed RFM69CW settings
#define MYNODE 5            // node ID 30 reserved for base station
#define freq RF12_433MHZ     // frequency
#define group 210            // network group 

#define LEDPIN 13
#define BAUDRATE 19200

#define DEBUG 

#define NOTHING_TO_SEND -1
#define N_TRIALS 5
#define N_LISTENERS 6
#define TX_CMD_Q_LEN 5
byte listenerNodeIDList[N_LISTENERS]={15,16,17,18,19,20};
//####################################################################
//Data Structure to be received 
//####################################################################
typedef struct
{
  int rx1;		    // received value
  int supplyV;              // payload voltage
} Payload;

static Queue<Payload> TX_payload_q[N_LISTENERS] = Queue<Payload>(TX_CMD_Q_LEN);
static Payload payload;//, TX_payload[N_LISTENERS][TX_CMD_Q_LEN];
static byte rssi2, rssi1, rssiMantisa;
static byte TX_counter[N_LISTENERS];
#define SET_CMD(p,v)      (p.supplyV = setByte(p.supplyV,v,1))
#define SET_NODEID(p,v)   (p.supplyV = setByte(p.supplyV,v,0))
#define SET_PORT(p,v)     (p.rx1 = setByte(p.rx1,v,1))
#define SET_TIMEOUT(p,v)  (p.rx1 = setByte(p.rx1,v,0))

#define GET_CMD(p)      (getByte(p.supplyV,1))
#define GET_NODEID(p)   (getByte(p.supplyV,0))
#define GET_PORT(p)     (getByte(p.rx1,1))
#define GET_TIMEOUT(p)  (getByte(p.rx1,0))

// Disable the front of the cmd queue for the nth listener.  This is done by pop'ing the
// queue if it is not empty and setting the TX retry counter to the max. re-trial value.
#define DISABLE_TXPKT(n) {						\
    if (!TX_payload_q[n].isEmpty()) TX_payload_q[n].pop();		\
    TX_counter[n]=N_TRIALS+1;						\
  }
#define ENABLE_TXPKT(n)  (TX_counter[n]=0) // Set the counter to zero, indicating that the TX pkt. needs is ready to be sent
#define TXPKT_ENABLED(n)  (TX_counter[n] < N_TRIALS) // Check if TX counter is less than max. allowed trials

//####################################################################
// The PacketBuffer class is used to generate the json string that is
// send via ethernet - JeeLabs
//####################################################################
class PacketBuffer : public Print
{
 public:
  PacketBuffer () : fill (0) {}
  const char* buffer() { return buf; }
  byte length() { return fill; }
  void reset() { for(fill=0;fill<150;fill++)buf[fill] = '\0';fill=0;}
  virtual size_t write(uint8_t ch)
  { if (fill < sizeof buf) buf[fill++] = ch; }  
  byte fill;
  char buf[150];
 private:
};
static PacketBuffer str;

//####################################################################
// Flow control varaiables
unsigned long lastPktSent[N_LISTENERS], lastPktRecvd=0;

//####################################################################
//####################################################################
//####################################################################

void setup() 
{
#ifdef DEBUG
  Serial.begin(BAUDRATE);
  Serial.println(F("Base Station: "));
  Serial.print(F(" Node: ")); Serial.print(MYNODE); 
  Serial.print(F(" Freq: ")); Serial.print(F("433MHz")); 
  Serial.print(F(" Network group: ")); Serial.println(group);
#if RF69_COMPAT
  Serial.println(F(" Working in RF69 Compatibility mode (RF12B Compat. mode actually)"));
#endif
#endif
  delay(10);
  rf12_initialize(MYNODE, freq,group,1600 /*freqOffset*/);
    
  initOOKRadio(); 
  Serial.println(F("Receiver ready"));
  
  // Set the node ID in the TX_payload to invalid value to indicate
  // that there is nothing to send yet.  Reset the re-try counter and
  // set the TX mode to OFF.
  for (byte i=0;i<N_LISTENERS;i++)
    {
      initTXPkt(i);
      TX_counter[i]=N_TRIALS+1;
      //      DISABLE_TXPKT(i);  
    }
  str.reset();            // Reset json string       

  // for (int i=0;i<N_LISTENERS;i++)
  //     TX_counter[i]=N_TRIALS+1;
}
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

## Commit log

2018-02-20 Added multipler for solenoid pulse width parameter. Updated the NOTES.
    This allows OTA setting of pulse width up to 255*255ms -- helpful for h/w debugging.
2018-03-09 Code cleanup, typo corrections, improvements in the notes.
    The little state-machine in unoserver was cleanedup, leading
    to removal of arbitrary delays that were earlier required.
    [RFM69_RxTx.ino, unoserver2.ino]
2018-03-15 Removed str.reset() in makeJSON().
    [unoserver2.ino]
2018-03-29 Node ID is now 16 + fixed a typo that prevented compilation (!)
    [RFM69_RxTx.ino]
2018-03-30 Cleaned up code + ADC enable/disable sequence in TinyTx.ino
2018-03-30 Using adc_{enable/disable} macros from power.h+delay reduced from 100ms to 10ms. Added a link to instructions for programming the ATT84 using the Arduino.
2018-04-13 Use hibernate to sleep (which also disables/enables adc)
2018-04-18 Fixes to make the multi-listener logic work.
    Ping-pong logic should work for multiple listeners active at the same
    time (which happens occassionally when the packets collide).
    [unoserver2.ino]
2018-04-22 Seems to work with multiple listeners.
    The printed Rx rx1 value is wrong (don't know why).
    [unoserver2.ino]
2018-04-22 Fixed RX rx1 printed value (it was printed without unpacking the int).
    Also added a check if nodeid in SEND_RFM commands is out of
    range. Without this check, an out-of-range value leads to re-boot of
    the basestation.
    [unoserver2.ino]
2018-04-23 Catch for out of range nodeID in SEND_RFM command tested to work.
    Previous commit had an error in the constructed error message as a
    JSON string.
    [unoserver2.ino]
2018-05-05 Adding test program for DRV8838 and PIN assigment for ATT84 in Readme
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2018-06-16 Testing a counter for an assured exit from Rx loop.
    These nodes go an infinite loop after some days of operation. From
    the battery voltage level after they are restarted, it appears they
    are stuck in an Rx (and hence spending battery power). This change is
    to exit the Rx loop after pre-determined number of Rx trials.
    [RFM69_RxTx.ino]
2018-06-17 Tested to work as before with MAX_RX_ATTEMPTS set to 50000. Also type-cast RFM69_READ_TIMEOUT to unsinged long when comparing with millis().
    Tests in progress to see if the problem in long runs is eliminated.
    [RFM69_RxTx.ino]
2018-06-23 TimeOfLastValveCmd is set only when an OPEN cmd is issued and reset to zero when the timeout is serviced.
    Delay for pulse width is via one piece of code (hopefully to reduce
    program size).
    [RFM69_RxTx.ino]
2018-06-27 DRV8838Tst: Changed pin names to EN and PH to match names on the chip docs. RFM69_RxTx: Explicitly shut the radio at the end of each loop().
2018-06-27 Added adc_enable/disable macros which do reduce power consuption. power_adc_enable/disable does not seem to work for me (don't know why).
2018-06-28 Using adc_enable/disable marcos with JeeLib code. These leave ATT84 consuming 20uAmp in sleep mode as against 200uAmp with power_adc_enable/disable.
2018-07-02 Adding TinyDRV8833 directory.
    This has code for test and RxTx with DRV8833 for solenoid control.
    Not yet tested.
2018-07-02 The MOSFET is switched-off after the activation pulse ends.
2018-07-06 Replaced SocketError with socket.error
    [myClientThread5.py]
2018-07-07 Enabled ADC before RFM operation.
    Adding tinytx3 schematic.
2018-07-13 Works with DRV8833+MOSFET switch.
    Most important change is to finish RFM operations first and shut it
    down before executing any command received via the radio.
    Tested a few times, but not yet sure if this is robust (it did not
    trigger the valve a few times -- don't know why).
2018-07-14 Set valve default ON time to 10sec., if supplied value is zero.
2018-07-20 Added commands as comments to test valve operation.
2018-07-22 Adds sets *any* packet to the gCurrentPacket array (per node).
    Earlier, only packets with rf_fail=0 were added. This change
    essentially also add the ACKpkt, which arrive with rf_fail=1 since
    they don't carry sensory data and only ACK of the commands exectued at
    the listener nodes.
2019-01-23 Added a few comments to remember the simulation code for testing that should go and/or replaced with rf12 code.
    [unoserver2.ino]
2019-01-31 Adding code of libraries required for compiling code in BaseStation (Arduino) and Nodes (ATTiny84) directories.
2019-02-02 Replaced QueueArray with array of Queue class.
    [unoserver2.ino]
2019-02-08 A working prototype for NaaradTopics2 thread to wake up registerd myClientThread5 threads.
2019-02-10 Hopefully a thread-safe version with multiple client threads registered with the main thread.
2019-02-14 Fixed a bug in ClientList.py and removed PacketID in unregister()+wait on lock and call unregister() myClientTh.py
    [ClientList.py, myClientThread5.py]
2019-02-17 Bug fixes in mySock::receive(). tmySock get the message as an argument. mySock::receive() was doing an rstrip on the partial chunk of the message, which would lead to loss of a whitespace in the mess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
    [mySock.py]
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2019-02-19 Corrected s/w arch. diagram; refactored modifyJSON out of PacketHandler.
    [NaaradUtils.py, PacketHandler.py, myClientThread5.py]
2019-02-20 Bug fixes in NaaradUtils.
    [NaaradUtils.py]
2019-02-20 Using "tnot" to determine dt in notify.py+removed a print statement in myCTh.
2019-02-20 Bug fix for the "notify" command (save the return value of Utils.addTimeStamp()).
    [myClientThread5.py]
2019-02-22 Packet lenght in send() is a fixed-length string. In prep to make receive more robust
    [mySock.py]
2019-02-25 Various fixes, not yet tested.
    [mySock.py]
2019-03-10 Inserted a "break" at the end of the "notify" cmd body. The thread exits for "notify" cmd finishes. Without this, a following RFM_SEND command doesn't execute on the sprinkler controller. With this c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
    [myClientThread5.py]
2019-03-13 Commented debug prints in mySock. Changes in notify to not issue the "close" cmd.
    [mySock.py]
2019-05-19 Adding the simultor code.
    It simulates the com port, uno and Pogo communication objects and uses the rest of the
    objects from NewServer. From a socket user point of view, this should look like real
    Naarad server.
2019-05-19 Adding the apps to get the current packet.
    getckpt: For the real Naarad server
    sgetckpt: For the simulated Naarad server. The only difference is the IP address it
    connects to!
2019-05-20 Event handler does open()/close() on the comPort as necessary.
    Clients should not need to do the open/close calls, which in case of
    error can leave the server in an inconsistent state.
    [myClientThread5.py]
2019-05-22 Using NAARAD_SHUTDOWN flag to exit threads in naaradsim.py and NaaradTopicSim.py
2019-05-22 Added settings5.NAARAD_SHUTDOWN flag and used in naarad.py and NaaradTopics2.py.
    The "shutdown" command issued twice will shut both server threads. The server process
    itself will stop thereafter.
    [NaaradTopic2.py, naarad.py, settings5.py]
2019-05-22 Removed topicsSubscriberList use in NaaradTopics2.py.
    The subscriber list model for the server is no longer in use. The
    server now works on a one-command-per-connection model (much like HTTP
    servers). Building commands that will keep a connection open is still
    possible.
    [NaaradTopic2.py]
2019-05-22 Typo correction in a message.
    [myClientThread5.py]
2019-05-23 Added message when the threads exit based on NAARAD_SHUTDOWN flag.
2019-05-25 messageHandler() returns a bool to indicate if the event loop should end.
    "done" is the only command that ends the event loop and the thread terminates.
2019-05-25 "notify" command also exits the event loop and terminates the thread.
2019-05-25 "Command not understood" also termintes the event loop and the thread.
2019-05-28 Added uuid-based thread identification in ClientList.py.
    In prep for adding continuous notification commmand and a command for
    discontinue continuous notification.
    Prototype handleContinuousNotify() method in myCTh5. Modified notify
    app to receive an info. packet with the threads uuid.
2019-05-28 Changes to make cnotify command work for continuous notification.
    notify.py: Some refactoring
    ClientList.py: Bug fix in continouousNotify()
    myClTh: Receive uuid in handleContNotify()
    NT.py: JSON packets with rf_fail:1 to test notification code.
    [ClientList.py, myClientThread5.py]
2019-05-29 De-register the client associated with this thread before exiting handleContNotify().
2019-05-30 Better handling of exceptions throw from abortContNotify+cosmetic changes in error strings.
    [ClientList.py, myClientThread5.py]
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2019-06-06 Circuit for DRV8833 based solenoid controller.
    This is the ciricut that has been tested to work.
2019-06-12 Reverting changes: replace " }}" by " }" and Utils.addTime returns just jsonStr.
    [NaaradTopic2.py, NaaradUtils.py]
2019-06-13 Schematic and TxT version of connections between RFM69 and Arduino UNO.
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2019-06-25 Fixed typo error in UniCodeDecodeError exception.
    [NaaradTopic2.py]
2019-06-27 Removed client control on comPort.open() .close().
    comPort's open/close are now internally managed, as it should be.
    myClTh: No uno.open()/.close() calls are made anywhere.
    comPort.py: Increment/decrement of users is internally protected by Lock.
    The "RFM_SEND" and "tell" commands were using uno.open()/close(). Now disabled.
    the "open" and "close" commands now only print a message.
    App/cmdnaard: Added a comment.
2019-07-08 Removed the second call to rf12_sendStart() in rfwrite() function.
    A single call to rf12_sendStart()/rf12_sendWait() combo seems
    required immediately after rf12_recvDone() via rf12_canSend()
    polling. Multiple calls to rf12_sendStart()/rf12_sendWait() seems
    to make the RFM69CW unstable. I.e. it freezes, sometime after a few
    days or operation, after which it does not receive *any* packets
    from *any* of the nodes. It **may** be capable of transmitting,
    but I haven't confirmed that.
    [unoserver2.ino]
2019-07-10 unoserver2.ino: Removed the second sendStart() in rfwrite(). This seems to remove the problem of radio freezing after few days of opration. Also changed the return type of readRFM69() to return the l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
    [NaaradTopic2.py, comPort.py, naarad.py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]
2019-07-11 Adding EAGLE files for the PCBs in used + Minor modification in NaSoftware.odg
    [SController-8833-routed.brd, SController-8833.brd, SController-8833.sch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]
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2019-07-19 unoserver2: Reset the radio if no packets are received for 10sec. NaTopic2: Write time.asctime() with the log messages on stdout. NaTopicSim: Produce node_id=3 packets every 5 iterations.
    [NaaradTopic2.py, unoserver2.ino]
2019-07-19 Reset the timer once the radio is initialized.
    [unoserver2.ino]
2019-07-24 This checkin was tested to get around the JeeLib bug due to which the radio freezes after ~2days of operation. unoserver2: Reset RFM69 if the time of last recvd pkt > 10sec. This reset is a workaroun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
    [NaaradTopic2.py, PacketHandler.py, naarad.py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]
2019-07-24 Typo fixes: Fixed missing semi-colons.
    [unoserver2.ino]
2019-07-25 Catch Ctrl-C and not exit the thread that listens on the naarad socket.
2019-08-07 - Adding sketch for 8833_ATT88 based controller. Not working yet - NaTopic2: Changed time.asctime() to time.srtftime().
    [DRV8833_ATT88_6Port.ino, NaaradTopic2.py, setPorts.cc]
2019-08-07 Added labels for the Pololu DRV8833 breakout board pins.
    [SController-8833.brd, SController-8833.sch]
2019-08-08 comPort.py: Removed residual debug print which came via the master branch.
2019-11-25 Chg: Removed printing of packets to the log for gethpkt.
2024-07-15 Fix in mySock.py::getNChar(). Encoding the initialization of val cnotify.py: Exception if the first arg is not cnotify serverinfo.py: Using the current IP address of the naaradserver
    [mySock.py]
